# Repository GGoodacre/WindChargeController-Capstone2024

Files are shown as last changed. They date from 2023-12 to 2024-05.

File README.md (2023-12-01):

# WindChargeController-Capstone2024
Wind Charge Controller for BEng Capstone 2024

## Objective
To develop a low cost, all-in-one Wind Charge Controller that caters to the average residential consumer considering wind power as a viable energy source for any relatively low power operations (<1kW).
This can be broken down into 3 main components:
* MPPT Formula
  *  We aim to make a Maximum Power Point Tracking algorithm specifically tuned for use with small scale wind turbines to maximimize efficiency and also very importantly, reduce turbine noise pollution 
* User Accessibility
  *  It is important for the product to be simple to install to cater to our target audience. Measures will be taken to design an intuitive interface and provide clear, user-friendly instructions, ensuring that even individuals with limited technical expertise can effortlessly install and operate the equipment
* Integration of additional devices
  *  We wish to offer users a seamless plug-and-play experience with other devices by utilizing the Victron environment and allowing integration with, for example, solar panels to ease the sporadic nature of wind power.

## LTspice
### System Overview
To get the LTspice simulation to run
1) Open "LTSpice\WCC\windchargecontroller.asc"
2) Go to "Tools > Control Panel > SPICE" and change "Solver" to "Alternate"
3) Copy paste the following into "Tools > Control Panel > Sym. & Lib. Search Paths > Symbol Search Path[*]"

>..\WCC_lib

### Benchmark
To get the benchmarks to run
1) Open "LTSpice\Benchmark\" and Open the file you want
2) Go to "Tools > Control Panel > SPICE" and change "Solver" to "Alternate"
3) Copy paste the following into "Tools > Control Panel > Sym. & Lib. Search Paths > Symbol Search Path[*]"

>..\WCC_lib

## Media

## Further Reading
.. put project proposal / abstract / conclusion here ..

## Credits

**Kurt Querengesser**

things

Kurt Querengesser

**Garnett Goodacre**

stuff

Garnett Goodacre

**Jaylin Lee**

asdf

**Michael Dao**

ghkj

TODO get jaylin and michael linkedin

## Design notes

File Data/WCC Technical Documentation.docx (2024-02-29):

WCC Technical Documentation

# 1. Features

# 2. Applications

# 3. Description

# 4. Diagrams

# 4.1. Pinout

# 4.2. Schematics

# 5. Specifications

# 6. Maximum Ratings

# 7. Implementation

# 8. Technical References

# 8.1. Victron/VenusOS

# 8.2. Modbus interfacing

Things to add to this document

- Features
- Applications
- Description
- Victron Python Lib
- OPKG
- Ratings
  - Wattage
  - Voltage
  - Current
  - Distortion, Harmonics, PF
- Pinouts
- Diagrams
- Schematics
- Labels
- Operation Guide
- Setup Guide
- Safety Precautions
- Efficiency
- Venus OS Registers
- Modbus
- References (Victron, VenusOS, etc.)
- Modbus doc

# 1 Heading 1

# 1.1 Heading 2

# 1.1.1 Heading 3

# Font

# Title of table

# Category

Example | 1234.5678

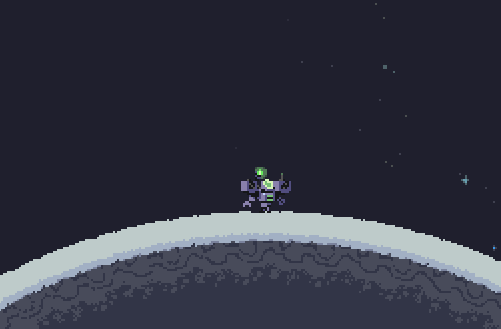
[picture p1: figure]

Figure 1 – Lil dude

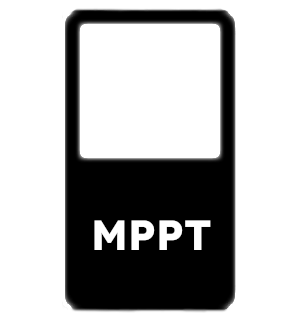
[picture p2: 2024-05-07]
PythonScripts/ConsoleTCP/mcpt_off.png

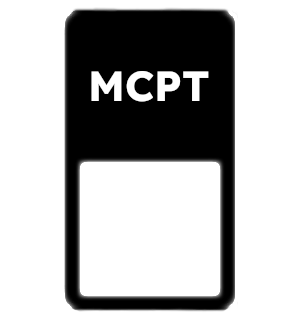
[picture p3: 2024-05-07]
PythonScripts/ConsoleTCP/mcpt_on.png

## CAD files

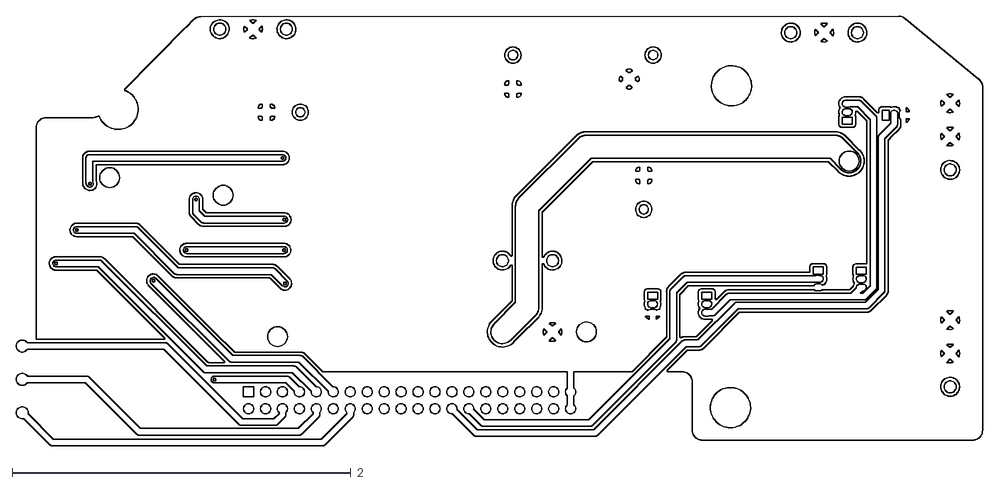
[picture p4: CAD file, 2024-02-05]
KiCad/output files/windchargecontroller-B_Cu.dxf
5.70 x 2.53

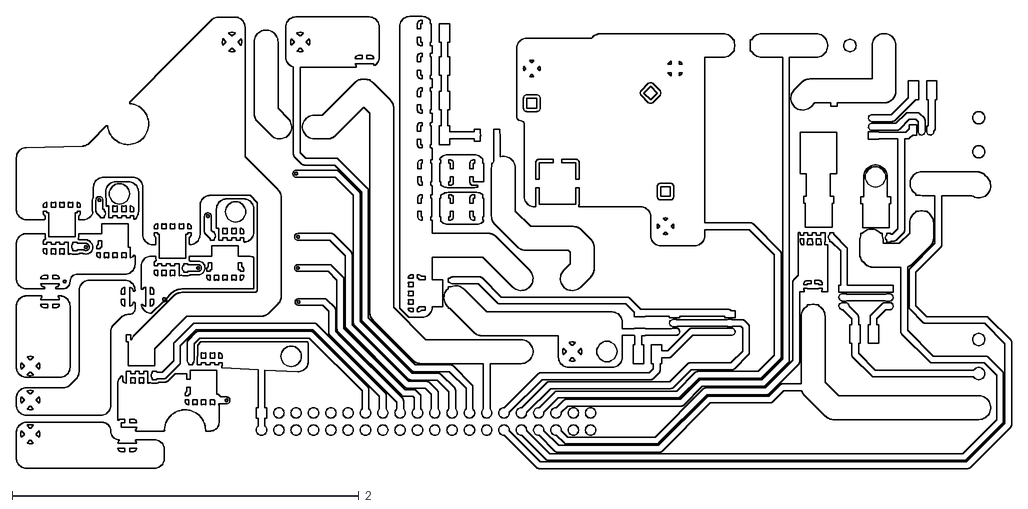
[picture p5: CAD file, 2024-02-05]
KiCad/output files/windchargecontroller-F_Cu.dxf
5.74 x 2.61

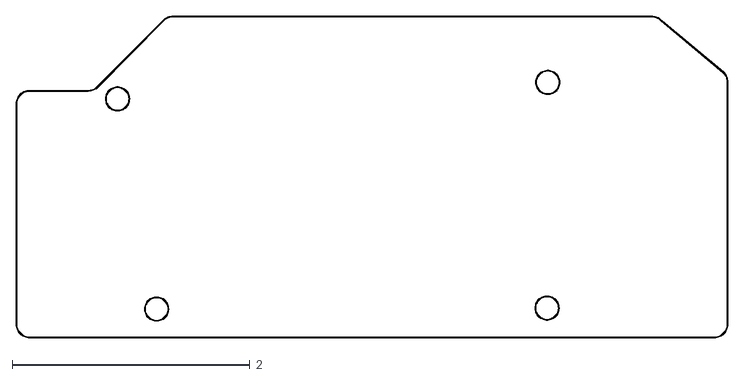
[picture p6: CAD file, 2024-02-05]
KiCad/output files/windchargecontroller-Edge_Cuts.dxf
5.99 x 2.70

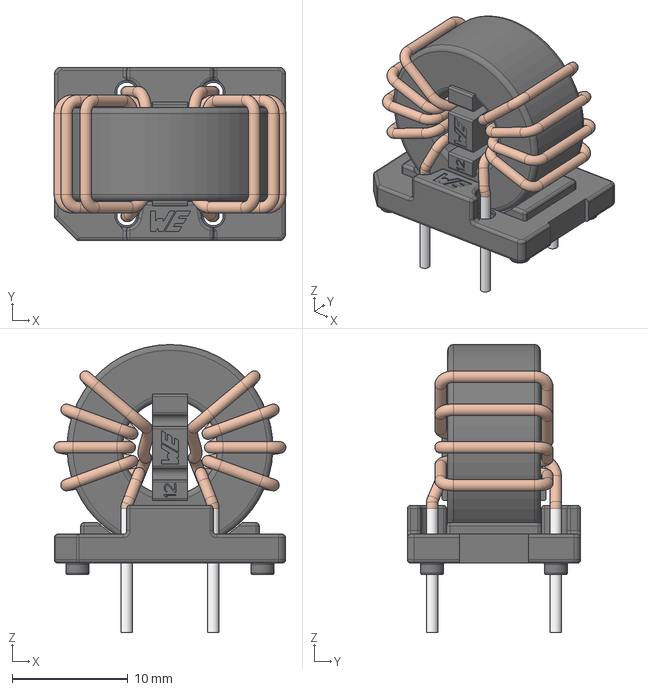
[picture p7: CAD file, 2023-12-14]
KiCad/models/steps/7448031002_Download_STP_7448031002_rev1.stp
20.0 x 15.0 x 24.9 mm

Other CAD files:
KiCad/output files/windchargecontroller-B_Adhesive.dxf
KiCad/output files/windchargecontroller-F_Adhesive.dxf
KiCad/output files/windchargecontroller-B_Mask.dxf
KiCad/output files/windchargecontroller-B_Paste.dxf
KiCad/output files/windchargecontroller-B_Silkscreen.dxf
KiCad/output files/windchargecontroller-F_Mask.dxf
KiCad/output files/windchargecontroller-F_Paste.dxf
KiCad/output files/windchargecontroller-F_Silkscreen.dxf

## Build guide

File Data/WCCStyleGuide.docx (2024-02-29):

Title

# 1 Heading 1

# 1.1 Heading 2

# 1.1.1 Heading 3

# Font

# Title of table

Category
Example


Figure 1 – Lil dude

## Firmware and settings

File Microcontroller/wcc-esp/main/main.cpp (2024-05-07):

/*
#include <stdio.h>
#include "Arduino.h"
#include "ControllerTCP.hpp"

extern "C" void app_main(void) {
    double a; // test variable
    a = 0; // some initial state
    ControllerTCP controller(a);
    while(1) {
        a = a + 1; // some ongoing operation performed
        ESP_LOGI("TEST", "a = %f", a);
        vTaskDelay(1000 / portTICK_PERIOD_MS);
    }
}
*/

#include "Arduino.h"
#include "HardwareControl.hpp"
#include "PowerSupplyControl.hpp"
#include "driver/adc.h"
#include "esp_adc_cal.h"
#include "freertos/FreeRTOS.h"
#include "freertos/task.h"
#include "driver/uart.h"
#include "ControllerTCP.hpp"

extern "C"
{
    #include <stdio.h>
    #include "esp_task_wdt.h"
}

extern "C"
{
    void app_main(void);
}

static const char* MAIN_TAG = "MAIN";
static const char* CSV_TAG = "CSV";
static const char* PWM_TAG = "PWM";

#define TXD_PIN (GPIO_NUM_43) // GPIO pin for TX
#define RXD_PIN (GPIO_NUM_44) // GPIO pin for RX
#define TURBINE_PIN 13


HardwareControl hw;
esp_adc_cal_characteristics_t adc1_chars;
void idleTsk(void * parameter);


void app_main(void)
{

    adc1_config_channel_atten(ADC1_CHANNEL_3, ADC_ATTEN_DB_11);
    adc1_config_channel_atten(ADC1_CHANNEL_4, ADC_ATTEN_DB_11);
    pinMode(TURBINE_PIN, OUTPUT);
    //digitalWrite(TURBINE_PIN, 1); ON
    digitalWrite(TURBINE_PIN, 0);
    

    esp_adc_cal_characterize(ADC_UNIT_1, ADC_ATTEN_DB_11, ADC_WIDTH_BIT_13, 0, &adc1_chars);

    float test_point;
    float Kp;
    float duty;
    int *adc_out;

    pinMode(LED_1, OUTPUT);
    digitalWrite(LED_1, LOW);


    //hw.setSetPoint(0, 3);
    hw.setAlgorithm(PID);
    //hw.setPWM(PWM_SEPIC, 40);

    esp_log_level_set(CONTROL_TAG, ESP_LOG_NONE);
    esp_log_level_set(SPI_TAG, ESP_LOG_NONE);
    esp_log_level_set(MAIN_TAG, ESP_LOG_NONE);
    esp_log_level_set(CSV_TAG, ESP_LOG_NONE);
    esp_log_level_set(PWM_TAG, ESP_LOG_NONE);
    esp_log_level_set(SEPIC_TAG, ESP_LOG_NONE);
    esp_log_level_set(RECTIFIER_TAG, ESP_LOG_NONE);

    xTaskCreate(
        idleTsk,    // Function that should be called
        "Idle Task",   // Name of the task (for debugging)
        10000,            // Stack size (bytes)
        NULL,            // Parameter to pass
        1,               // Task priority
        NULL             // Task handle
    );
}

void idleTsk(void * parameter);


void idleTsk(void * parameter)
{
    // passing hw into the controller class to do stuff
    static ControllerTCP controller(hw);
    for(;;)
    {
        hw.update();
        
        //controller send data
        /*
        _device_values_t measurements;
        for(int i = 0; i < TOTAL_MEASUREMENT_DEVICES; i++)
        {
            if(hw.getDeviceEN(i))
            {
                measurements = hw.getDeviceParams(i);
                ESP_LOGI(CSV_TAG,"%lld,%d,%f,%f,%f,%f", esp_timer_get_time(), i, measurements.current, measurements.vbus, measurements.power, measurements.dietemp);
            }
        }

        for(int i = 0; i < TOTAL_PWM_VALUES; i++) {
            ESP_LOGI(PWM_TAG, "%lld,%d,%f,%d", esp_timer_get_time(), i, hw.getPWM(i), hw.getSetPoint(i));
        }
        */
    }
}

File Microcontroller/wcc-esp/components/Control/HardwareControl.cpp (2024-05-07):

#include <stdio.h>
#include "HardwareControl.hpp"

HardwareControl::HardwareControl() : 
    Control(LEDC_TIMER_8_BIT, PWM_FREQUENCY, LEDC_TIMER_0, MAX_CURRENT, R_SHUNT)
{
    _algorithm = MANUAL;
    _sepic_pwm_setpoint = 0;

    _pwm_values[PWM_RECTIFIER].duty_cycle = 100;
    _pwm_values[PWM_RECTIFIER].channel = RECTIFIER_INDEX;
    _pwm_values[PWM_RECTIFIER].device_pin = RECTIFIER_PIN;
    _pwm_values[PWM_RECTIFIER].invert = 1;
    _pwm_values[PWM_RECTIFIER].setpoint = RECTIFIER_SETPOINT;
    _pwm_values[PWM_RECTIFIER].pid = QuickPID(&_rectifier_input, &_pwm_values[PWM_RECTIFIER].duty_cycle, &_pwm_values[PWM_RECTIFIER].setpoint);
    _pwm_values[PWM_RECTIFIER].pid.SetTunings(RECTIFIER_Kp, RECTIFIER_Ki, RECTIFIER_Kd);
    _pwm_values[PWM_RECTIFIER].pid.SetOutputLimits(0, 100);
    _pwm_values[PWM_RECTIFIER].pid.SetMode(1);
    _pwm_values[PWM_RECTIFIER].pid.SetSampleTimeUs(1000);

    _pwm_values[PWM_SEPIC].duty_cycle = 30;
    _pwm_values[PWM_SEPIC].channel = SEPIC_INDEX;
    _pwm_values[PWM_SEPIC].device_pin = SEPIC_PIN;
    _pwm_values[PWM_SEPIC].invert = 0;
    _pwm_values[PWM_SEPIC].setpoint = SEPIC_SETPOINT;
    _pwm_values[PWM_SEPIC].pid = QuickPID(&_sepic_pwm_input, &_pwm_values[PWM_SEPIC].duty_cycle, &_sepic_pwm_setpoint);
    _pwm_values[PWM_SEPIC].pid.SetTunings(SEPIC_Kp, SEPIC_Ki, SEPIC_Kd);
    _pwm_values[PWM_SEPIC].pid.SetMode(1);
    _pwm_values[PWM_SEPIC].pid.SetOutputLimits(20, 80);
    _pwm_values[PWM_SEPIC].pid.SetSampleTimeUs(1000);

    _pwm_values[PWM_PS1].duty_cycle = 100;
    _pwm_values[PWM_PS1].channel = PS1_INDEX;
    _pwm_values[PWM_PS1].device_pin = PS1_PIN;
    _pwm_values[PWM_PS1].invert = 0;
    _pwm_values[PWM_PS1].pid = QuickPID(&_devices[DEVICEINDEX_R8_BATTERY].power, &_pwm_values[PWM_PS1].duty_cycle, &_pwm_values[PWM_PS1].setpoint);
    _pwm_values[PWM_PS1].pid.SetTunings(PS1_Kp, PS1_Ki, PS1_Kd);
    _pwm_values[PWM_PS1].pid.SetMode(1);

    _pwm_values[PWM_PS2].duty_cycle = 0;
    _pwm_values[PWM_PS2].channel = PS2_INDEX;
    _pwm_values[PWM_PS2].device_pin = PS2_PIN;
    _pwm_values[PWM_PS2].invert = 0;

    _devices[DEVICEINDEX_R1_THREEPHASE].en = false;
    _devices[DEVICEINDEX_R1_THREEPHASE].en_measurement = {0, 1, 0, 1, 1, 0, 0};
    _devices[DEVICEINDEX_R1_THREEPHASE].device_pin = R1_AC_THREEPHASE;

    _devices[DEVICEINDEX_R2_THREEPHASE].en = false;
    _devices[DEVICEINDEX_R2_THREEPHASE].en_measurement = {0, 1, 0, 1, 1, 0, 0};
    _devices[DEVICEINDEX_R2_THREEPHASE].device_pin = R2_AC_THREEPHASE;

    _devices[DEVICEINDEX_R3_THREEPHASE].en = false;
    _devices[DEVICEINDEX_R3_THREEPHASE].en_measurement = {0, 1, 0, 1, 1, 0, 0};
    _devices[DEVICEINDEX_R3_THREEPHASE].device_pin = R3_AC_THREEPHASE;

    _devices[DEVICEINDEX_R4_RECTIFIED].en = true;
    _devices[DEVICEINDEX_R4_RECTIFIED].en_measurement = {0, 1, 0, 1, 1, 0, 0};
    _devices[DEVICEINDEX_R4_RECTIFIED].device_pin = R4_DC_RECTIFIED;

    _devices[DEVICEINDEX_R7_BUCK].en = true;
    _devices[DEVICEINDEX_R7_BUCK].en_measurement = {0, 1, 0, 1, 1, 0, 0};
    _devices[DEVICEINDEX_R7_BUCK].device_pin = R7_DC_BUCK;

    _devices[DEVICEINDEX_R8_BATTERY].en = false;
    _devices[DEVICEINDEX_R8_BATTERY].en_measurement = {0, 1, 0, 1, 1, 0, 0};
    _devices[DEVICEINDEX_R8_BATTERY].device_pin = R8_DC_BATTERY;

    _devices[DEVICEINDEX_R9_DUMP].en = false;
    _devices[DEVICEINDEX_R9_DUMP].en_measurement = {0, 1, 0, 1, 1, 0, 0};
    _devices[DEVICEINDEX_R9_DUMP].device_pin = R9_DC_DUMP;

    pinMode(HIGHSIDE_RECTIFIER_PIN, OUTPUT);
    digitalWrite(HIGHSIDE_RECTIFIER_PIN, LOW);

    config();
}

HardwareControl::~HardwareControl()
{
}

void HardwareControl::PID_control()
{   
    _rectifier_input = _devices[DEVICEINDEX_R4_RECTIFIED].vbus;
    _sepic_pwm_input = _pwm_values[PWM_SEPIC].duty_cycle/100;
    _sepic_pwm_setpoint = (SEPIC_SETPOINT + diode_drop) / (SEPIC_SETPOINT + diode_drop + _devices[DEVICEINDEX_R4_RECTIFIED].vbus);
    ESP_LOGI(SEPIC_TAG, "Rectified VBUS: %f   Sepic VBUS: %f   Desired PWM:  %f   Current PWM: %f", _devices[DEVICEINDEX_R4_RECTIFIED].vbus, _devices[DEVICEINDEX_R7_BUCK].vbus, _sepic_pwm_setpoint, _pwm_values[PWM_SEPIC].duty_cycle);
    ESP_LOGI(RECTIFIER_TAG, "Rectified VBUS: %f   Current PWM: %f", _devices[DEVICEINDEX_R4_RECTIFIED].vbus, _pwm_values[PWM_RECTIFIER].duty_cycle);

    if(_pwm_values[PWM_SEPIC].pid.Compute()) _pwm.setDUTY(_pwm_values[PWM_SEPIC].duty_cycle, _pwm_values[PWM_SEPIC].channel);
    if(_pwm_values[PWM_RECTIFIER].pid.Compute()) _pwm.setDUTY(_pwm_values[PWM_RECTIFIER].duty_cycle, _pwm_values[PWM_RECTIFIER].channel);
}

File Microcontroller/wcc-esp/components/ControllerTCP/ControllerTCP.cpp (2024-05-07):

#include "ControllerTCP.hpp"

ControllerTCP::ControllerTCP(HardwareControl &hw) : hw(hw) {
    _tag = "TCP Controller";
    init_netif_helper();
    xTaskCreate(&run_tcp_console_trampoline, "tcp_console_task", 4096, this, 9, &_tcp_console);
    init_mb_master_helper();
    xTaskCreate(&run_send_data_trampoline, "mb_send_data", 4096, this, 9, &_mb_send_data);
}

void ControllerTCP::wifi_connect_hdl_en(void* arg, esp_event_base_t event_base, int32_t event_id, void* event_data) {
    ControllerTCP* enable_event_handler = (ControllerTCP*) arg;
    enable_event_handler -> wifi_connect_hdl(arg, event_base, event_id, event_data);
}

void ControllerTCP::wifi_connect_hdl(void* arg, esp_event_base_t event_base, int32_t event_id, void* event_data)
{
    static int s_retry_num = 0;
    if (event_base == WIFI_EVENT && event_id == WIFI_EVENT_STA_START) {
        ESP_ERROR_CHECK(esp_wifi_connect());
    } 
    else if (event_base == WIFI_EVENT && event_id == WIFI_EVENT_STA_DISCONNECTED) {
        if (s_retry_num <= MAX_RETRIES) {
            ESP_ERROR_CHECK(esp_wifi_connect());  
            s_retry_num++;
            ESP_LOGE(_tag, "retrying connection to wifi");
        }
        else {
            xEventGroupSetBits(_s_wifi_event_group, WIFI_FAIL_BIT);
        }
    }
    else if (event_base == IP_EVENT && event_id == IP_EVENT_STA_GOT_IP) {
        ip_event_got_ip_t* got_ip_event = (ip_event_got_ip_t*) event_data;
        ESP_LOGI(_tag, "successfully connected to wifi with ip:" IPSTR, IP2STR(&got_ip_event->ip_info.ip));
        s_retry_num = 0;
        _connected_to_wifi = true;
        xEventGroupSetBits(_s_wifi_event_group, WIFI_CONNECTED_BIT);
    }
}

void ControllerTCP::init_netif_helper() {
    ESP_ERROR_CHECK(nvs_flash_init());

    _s_wifi_event_group = xEventGroupCreate();

    ESP_ERROR_CHECK(esp_netif_init());
    ESP_ERROR_CHECK(esp_event_loop_create_default());

    _mb_comm_info.ip_netif_ptr = (void*)esp_netif_create_default_wifi_sta();

    wifi_init_config_t _wifi_init_config = WIFI_INIT_CONFIG_DEFAULT();
    ESP_ERROR_CHECK(esp_wifi_init(&_wifi_init_config));

    _connected_to_wifi = false;
    esp_event_handler_instance_t instance_any_id;
    esp_event_handler_instance_t instance_got_ip;
    ESP_ERROR_CHECK(esp_event_handler_instance_register(WIFI_EVENT, ESP_EVENT_ANY_ID, &wifi_connect_hdl_en, this, &instance_any_id));
    ESP_ERROR_CHECK(esp_event_handler_instance_register(IP_EVENT, IP_EVENT_STA_GOT_IP, &wifi_connect_hdl_en, this, &instance_got_ip));

    wifi_config_t wifi_sta_config = {
        .sta = {
            .ssid = {'a','d','a','o','4'},
            .password = {'1','2','3','4','5','6','7','8'},
            .pmf_cfg = {
                .capable = true,
                .required = false
            },
        },
    };

    ESP_ERROR_CHECK(esp_wifi_set_mode(WIFI_MODE_STA));
    ESP_ERROR_CHECK(esp_wifi_set_config(WIFI_IF_STA, &wifi_sta_config));
    ESP_ERROR_CHECK(esp_wifi_start());

    EventBits_t bits = xEventGroupWaitBits(_s_wifi_event_group,
            WIFI_CONNECTED_BIT | WIFI_FAIL_BIT,
            pdFALSE,
            pdFALSE,
            portMAX_DELAY);

    if (bits & WIFI_CONNECTED_BIT) {
        ESP_LOGI(_tag, "connected to ap SSID:%s password:%s", "adao4", "12345678");
    } 
    else if (bits & WIFI_FAIL_BIT) {
        ESP_LOGI(_tag, "Failed to connect to SSID:%s, password:%s", "adao4", "12345678");
    } 
    else {
        ESP_LOGE(_tag, "UNEXPECTED EVENT");
    }

    ESP_ERROR_CHECK(esp_event_handler_instance_unregister(IP_EVENT, IP_EVENT_STA_GOT_IP, instance_got_ip));
    ESP_ERROR_CHECK(esp_event_handler_instance_unregister(WIFI_EVENT, ESP_EVENT_ANY_ID, instance_any_id));
    vEventGroupDelete(_s_wifi_event_group);
}

void ControllerTCP::run_tcp_console_trampoline(void* arg) {
    ControllerTCP* local_tcp_console = (ControllerTCP*) arg;

    local_tcp_console->run_tcp_console();
}
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

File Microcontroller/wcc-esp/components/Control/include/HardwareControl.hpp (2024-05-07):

#pragma once
#include "Control.hpp"
#include "QuickPID.h"
#include <array>

enum HARDWARE_ALGORITHMS {
    MPPT,
    MCPT
};

#define TOTAL_MEASUREMENT_DEVICES 7

enum PWM_INDEX {
    PWM_RECTIFIER,
    PWM_SEPIC,
    PWM_PS1,
    PWM_PS2
};

enum DEVICE_INDEX {
    DEVICEINDEX_R1_THREEPHASE,
    DEVICEINDEX_R2_THREEPHASE,
    DEVICEINDEX_R3_THREEPHASE,
    DEVICEINDEX_R4_RECTIFIED,
    DEVICEINDEX_R7_BUCK,
    DEVICEINDEX_R8_BATTERY,
    DEVICEINDEX_R9_DUMP,
};

#ifndef CS_PINS
  #define R1_AC_THREEPHASE  39
  #define R2_AC_THREEPHASE  38
  #define R3_AC_THREEPHASE  37
  #define R4_DC_RECTIFIED   2
  #define R7_DC_BUCK        42
  #define R8_DC_BATTERY     41
  #define R9_DC_DUMP        40
#endif

#ifndef LED_PINS
    #define LED_1 16
    #define LED_2 15
    #define LED_3 7
    #define LED_4 6
    #define LED_5 5
    #define LED_6 4
#endif

#ifndef POWERELECPINS
    #define RECTIFIER_PIN   34
    #define HIGHSIDE_RECTIFIER_PIN 33
    #define SEPIC_PIN       1
    #define PS1_PIN        19
    #define PS2_PIN        20
#endif

#ifndef PWM_PARAMETERS
  #define RECTIFIER_INDEX   LEDC_CHANNEL_0
  #define SEPIC_INDEX       LEDC_CHANNEL_1
  #define PS1_INDEX        LEDC_CHANNEL_3
  #define PS2_INDEX        LEDC_CHANNEL_4
  #define TOTAL_PWM_VALUES 4
  #define PWM_FREQUENCY     10000
#endif

#define MAX_CURRENT 10
#define R_SHUNT 0.01

#define diode_drop 1.4
#define SEPIC_SETPOINT 0.6
#define RECTIFIER_SETPOINT 5
#define PS1_SETPOINT 1000

#define SEPIC_Kp 10
#define SEPIC_Ki 2
#define SEPIC_Kd 0

#define RECTIFIER_Kp 20
#define RECTIFIER_Ki 20
#define RECTIFIER_Kd 0

#define PS1_Kp 0
#define PS1_Ki 0
#define PS1_Kd 0

static const char* SEPIC_TAG = "SEPIC";
static const char* RECTIFIER_TAG = "RECTIFIER";

class HardwareControl : public Control<TOTAL_PWM_VALUES, TOTAL_MEASUREMENT_DEVICES> {
    public:
        HardwareControl();
        ~HardwareControl();
    private:
        
        void PID_control();
        float _sepic_pwm_setpoint;
        float _sepic_pwm_input;
        float _rectifier_input;
};

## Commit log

2023-10-06 powerswitch, adc added
    cleaned up other stuff, added a gitignore
2023-10-11 updated powerswitch, overall changes
    changed from nmos to pmos in powerswitch
2023-10-24 added custom FET model, changed inductor values
2023-11-08 Component selection started
    Took data, added a data section, started selecting components, made a BOM, making a mosfet driver
    [ChokeCouplingCoeff.xlsx, Wind Turbine BOM1.xlsx]
2023-11-08 Cleaned up repo, added mosfet driver
    removed old folders, renamed files to make more sense, made search path simpler and put all symbols/schematics in one place. Made a simple bjt totem pole mosfet driver and started adding to the BOM
    [Wind Turbine BOM1.xlsx]
2023-11-23 started KiCad work, working on BOM
    [Wind Turbine BOM1.xlsx, windchargecontroller.kicad_pcb, windchargecontroller.kicad_sch]
2023-11-28 Worked on KiCad
    added a bunch of stuff to schematic and started pcb design
    [windchargecontroller.kicad_pcb, windchargecontroller.kicad_sch]
2023-11-30 Worked on schematic and pcb
    added inductor, moved stuff around on pcb into general area to get a rough idea for size. Getting schematic checked for problems but almost done
    [windchargecontroller.kicad_pcb, windchargecontroller.kicad_sch]
2023-12-01 updated kicad and commented ltspice
    fixed an incorrect wiring situation in kicad schematic and started process of labelling ltspice schematics
    [windchargecontroller.kicad_pcb, windchargecontroller.kicad_sch]
2023-12-09 WCC V1.0
    placed components and made first version of PCB
    [windchargecontroller.kicad_pcb, windchargecontroller.kicad_sch]
2023-12-14 updated WCC Schematic and made measurement board
    [7448031002_Download_STP_7448031002_rev1.stp, WCC_autogen_BOM.csv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]
2023-12-22 push before i swap out diodes for mosfets
    [windchargecontroller.kicad_pcb, windmeasureboard.kicad_pcb, windmeasureboard.kicad_sch]
2024-01-03 6fets + DC bus
    replaced rectifier diodes with mosfets for full 6 mosfet, removed their resistors due to space constraints. DC bus now directly goes into one of the power outputs + various board fixes. DRC now errorless.
    [windchargecontroller.kicad_pcb, windchargecontroller.kicad_sch]
2024-01-08 WCC V.1.1
    [WCC_autogen_BOM.csv, Wind Turbine BOM1.xlsx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]
2024-01-10 updated to PCB V.1.2
    made changes based on mentor's comments; mounting holes no longer grounded, reduced ground loops, moved Q12 and Q13 to allow for extra ground clearance, grounds no longer adjacent to power, and various other small fixes
    [windchargecontroller.kicad_pcb, windchargecontroller.kicad_sch]
2024-02-05 cleaning up
    [WCC_autogen_BOM.csv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]
2024-02-05 Prototype board create
    [prototypemeasurement.kicad_pcb, prototypemeasurement.kicad_sch, windchargecontroller-B_Adhesive.dxf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]
2024-02-06 esp32 project folder
    entire vscode project folder for the esp32
    currently has code only implemented w/ comments in main()
    will push a modular version later
2024-02-08 started work on pcb v2.0
    [windchargecontroller.kicad_pcb]
2024-02-09 started work on Measure Board V1
    [windchargecontroller.kicad_pcb, windchargecontroller.kicad_sch, windmeasureboard.kicad_sch]
2024-02-09 SPI builds
2024-02-09 esp32_modbus_tcp fully modular
    all modbus tcp code initially clumped in the main file is now properly separated into a modbus_tcp.c and modbus_tcp.h along with main.c with 0 build errors as of current
2024-02-15 Basics working for esp
    [prototypemeasurement-Edge_Cuts.gbr, prototypemeasurement-F_Adhesive.gbr, prototypemeasurement-F_Cu.gbr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]
2024-02-15 WCC 2.0
    ready for it to be roasted again
    [windchargecontroller.kicad_pcb]
2024-02-15 worked on measure board
    [windmeasureboard.kicad_pcb, windmeasureboard.kicad_sch]
2024-02-20 functional esp32 modbus tcp
    will add further qol and refinement as required
2024-02-22 big 1.0 release
    further improved modbus tcp
    added functional python scripts for modifying attributes.csv and adding custom dbus services to the raspberry pi as we need
    comfortably ready for power measurement integration with this revision going forward
2024-02-23 Testing SPI on IN229
2024-02-29 V1 Measure Board Finished
    Also started manual data collection for turbine and started updating files to kicad V7
    [MotorEfficiencyData.xlsx, measurechips.kicad_sch, windmeasureboard.kicad_pcb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]
2024-03-12 started V2 WMB
    fixed PSU issue
    [windchargecontroller.kicad_pcb, windmeasureboard.kicad_pcb, windmeasureboard.kicad_sch]
2024-03-14 Finished WMB V2.1
    [windmeasureboard.kicad_pcb, windmeasureboard.kicad_sch]
2024-03-17 WMB 2.2 pushed and ordered
    [windmeasureboard.kicad_pcb, windmeasureboard.kicad_sch]
2024-03-29 added some kicad components
    [windmeasureboard.kicad_pcb]
2024-04-04 Update Control
    [2024-03-25_ConstantSpeedTest.xlsx]
2024-05-06 prelim button
2024-05-07 PID working
2024-05-07 New Buttons
